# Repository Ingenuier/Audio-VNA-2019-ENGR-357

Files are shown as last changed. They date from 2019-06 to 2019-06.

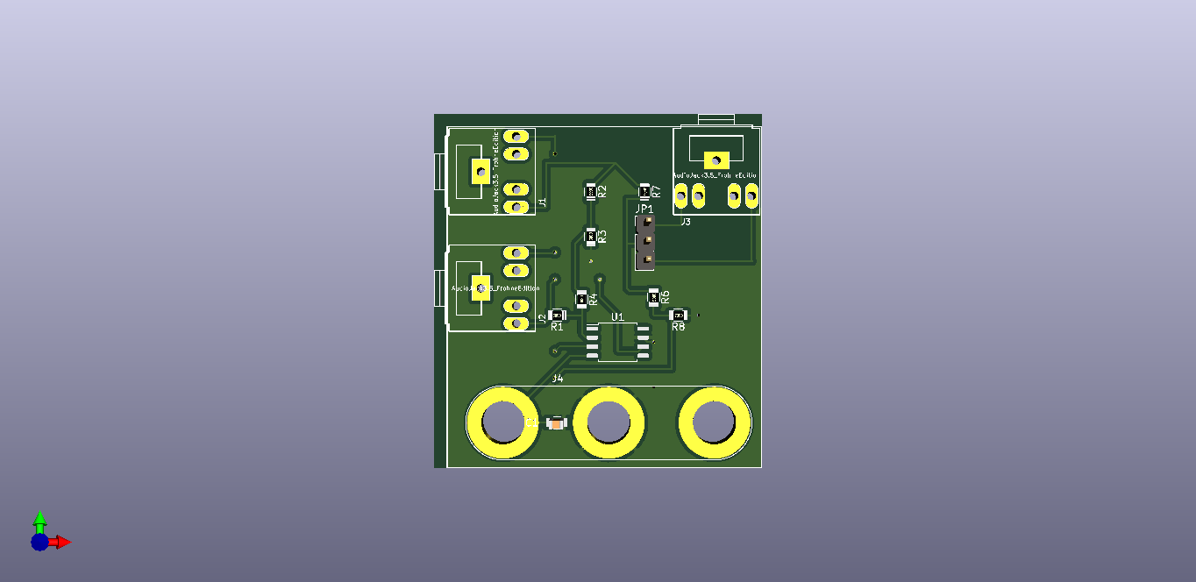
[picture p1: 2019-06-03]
KiCad/Dominick Christensen/VNA2019_KiCad Final Design/VNA2019Soundcard/VNA2019soundcard PCB PNG.png

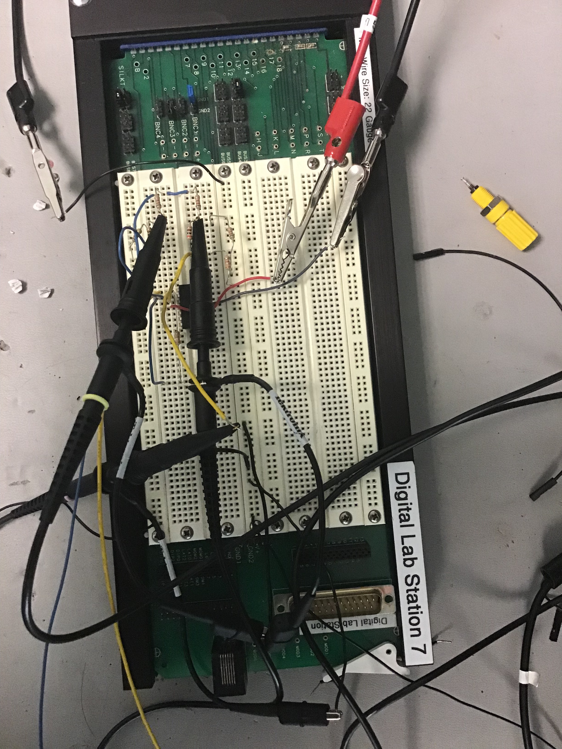
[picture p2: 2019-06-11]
PrototypeReflectionBridge.jpg

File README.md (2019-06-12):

# Audio-VNA-2019-ENGR-357
Audio Frequency VNA Project for Engineering Electronics II
Christian Terrado

These are the setup instructions for the Reflection Bridge and Sound Card, these instructions were made with the Windows OS in mind.

Software Instructions:

    -git clone the repository ( https://github.com/Ingenuier/Audio-VNA-2019-ENGR-357.git )
    -Install Python 3.7.2 and your preferred tool for executing code 
        -Tests were done using a text editor and terminal
    -In terminal, import:
        -NumPy
        -matplotlib
        -skrf (had a little trouble with this one)
        -sounddevice
        -soundfile

Hardware Instructions:

    -Plug in a 7.1 Ch Sound Card into your computer
    -Take two male to male 3.5 mm audio jacks and attach the soundcard output (headphones) into the input jack on the PCB
        -Do the same with the sound card input (microphone) and plug it into the output jack on the PCB
        -Top audio plug is input jack and bottom audio plug is output jack 
    -Use the screw terminals to supply the PCB with +/- 15V and a connection to ground on a Power Supply
        -Old physical model did not do a great job at labeling so it would be best to refer to the schematic
        -In my tests I used a HP Triple Output Power Supply
    -Use third male to male jack to connect the Device Under Test to the D.U.T Port on the PCB
        -far right audio jack is the device under test
    -Pick which channel will be tested on the reflection bridge using the jumpers next to the D.U.T Port
        -top jumper is ring, bottom is tip. 
    -Turn on the power and run the code on the PC

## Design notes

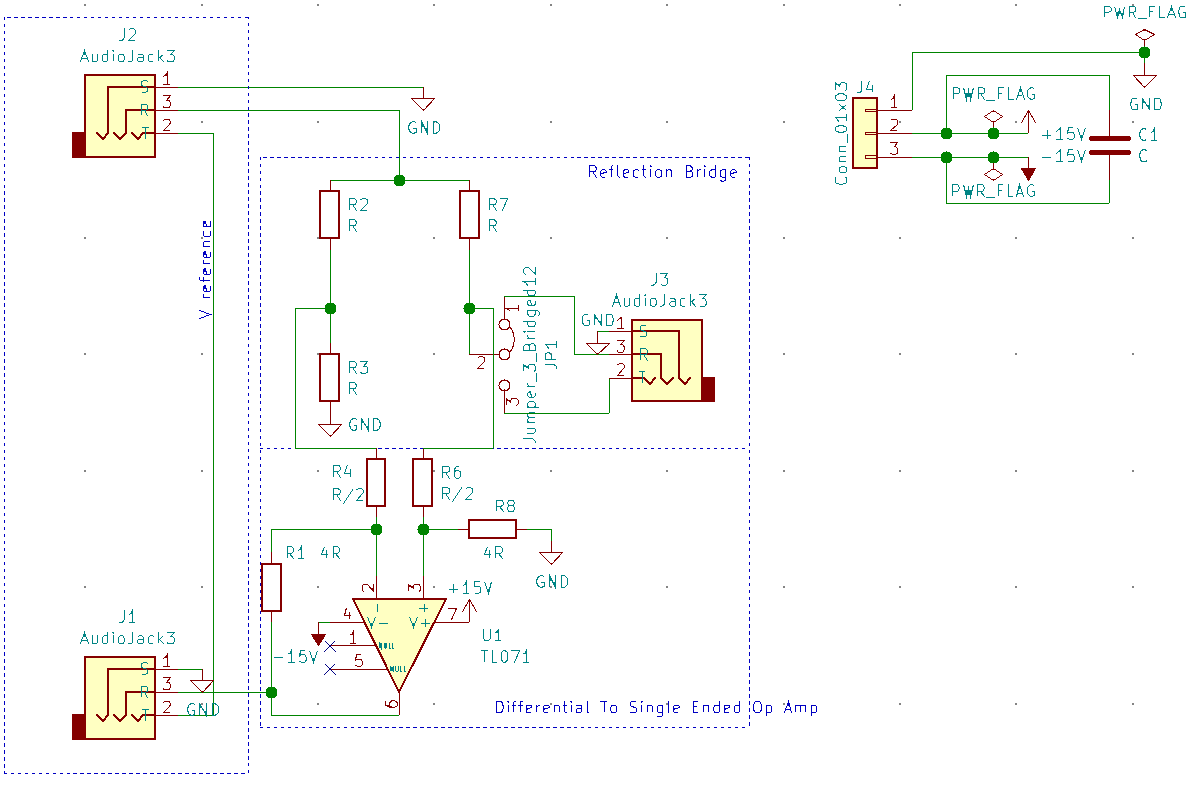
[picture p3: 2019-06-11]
CropOfSchematic.png

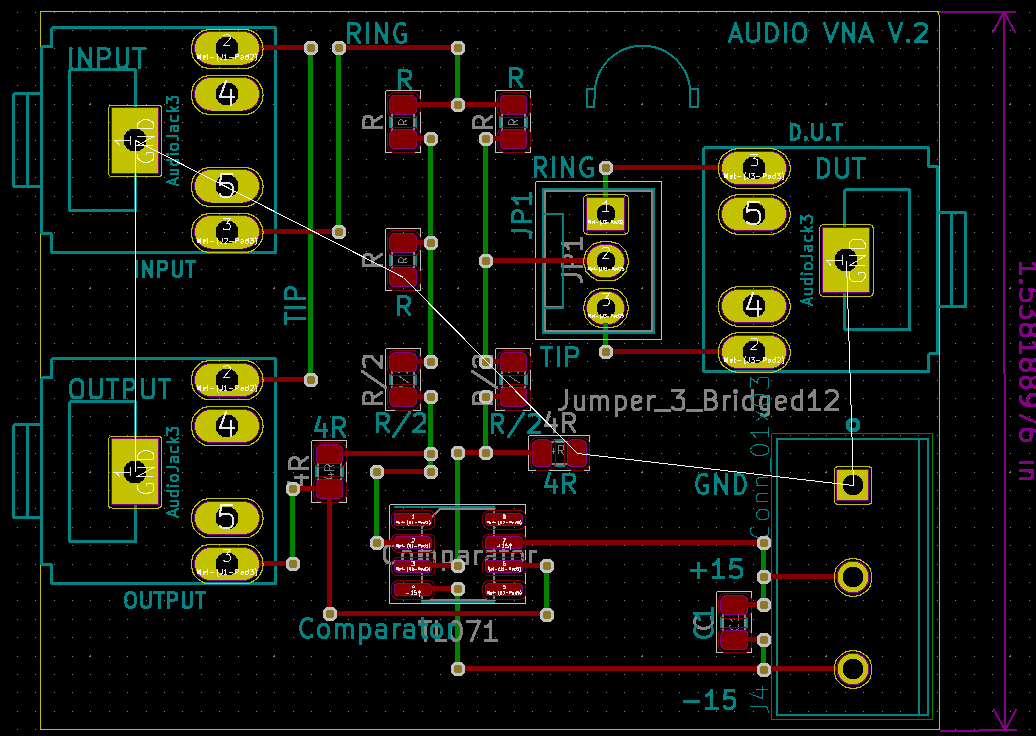
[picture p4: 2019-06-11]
CropOfVNAPCB.png

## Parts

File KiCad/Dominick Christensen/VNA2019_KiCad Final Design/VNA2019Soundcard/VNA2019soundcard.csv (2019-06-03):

Id | Designator | Package | Quantity | Designation | Supplier and ref
1 | J1,J2,J3 | Tayda_3.5mm_stereo_TRS_jack_A-853 | 3 | AudioJack3.5_FrohneEdition
2 | J4 | Banana_Jack_3Pin | 1 | Conn_01x03
3 | U1 | SOIC-8_5.23x5.23mm_P1.27mm | 1 | TL071
4 | R8,R7,R6,R4,R3,R2,R1 | R_0805 | 7 | R
5 | C1 | C_0805 | 1 | C
6 | JP1 | PinHeader_1x03_P2.54mm_Vertical | 1 | Jumper_3_Bridged12

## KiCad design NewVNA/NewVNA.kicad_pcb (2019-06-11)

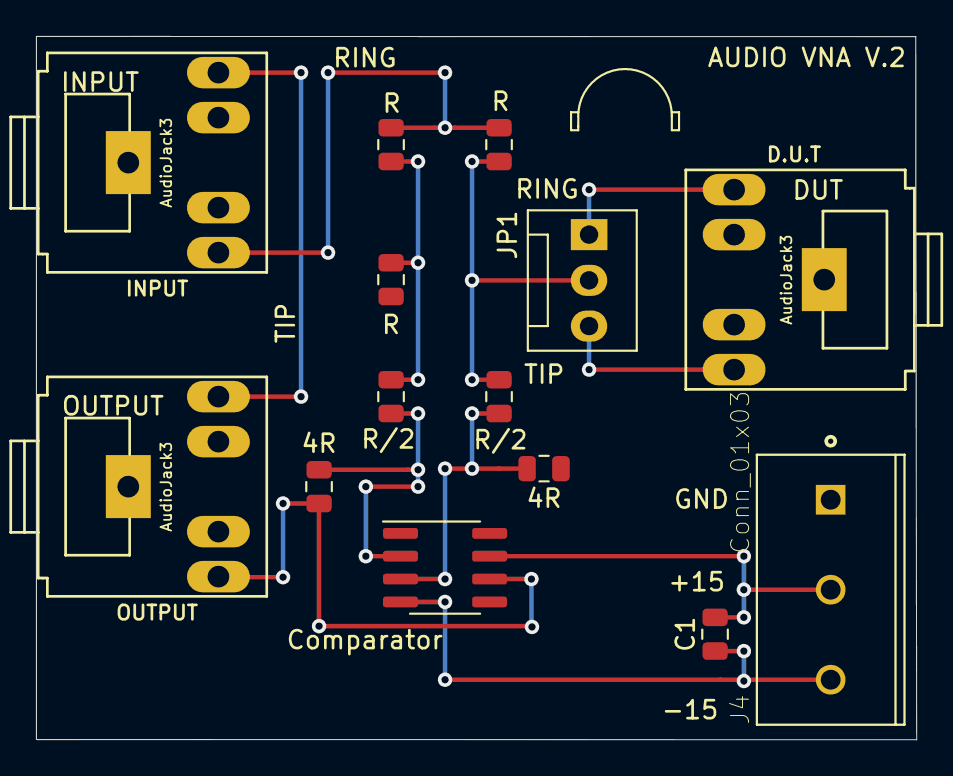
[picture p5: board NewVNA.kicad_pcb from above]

Board: 2 copper layers, 48.9 x 39.1 mm, 14 parts (0 on the bottom side), 12 nets.

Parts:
4R, 4R#2: 4R; R_0805_2012Metric
C1: C; C_0805_2012Metric
Comparator: TL071; SOIC-8_3.9x4.9mm_P1.27mm
D.U.T: AudioJack3; Tayda_3.5mm_stereo_TRS_jack_A-853
INPUT: AudioJack3; Tayda_3.5mm_stereo_TRS_jack_A-853
J4: Conn_01x03; TE_282836-3
JP1: Jumper_3_Bridged12; FanPinHeader_1x03_P2.54mm_Vertical
OUTPUT: AudioJack3; Tayda_3.5mm_stereo_TRS_jack_A-853
R: R; R_0805_2012Metric
R#2, R#3: R; R_0805_2012Metric
R/2, R/2#2: R/2; R_0805_2012Metric

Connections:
+15V: C1.1, Comparator.7, J4.2
-15V: C1.2, Comparator.4, J4.3
GND: 4R.1, D.U.T.1, INPUT.1, J4.1, OUTPUT.1, R#2.2
unnamed: INPUT.2, OUTPUT.2
unnamed: 4R#2.2, Comparator.6, OUTPUT.3
unnamed: INPUT.3, R.1, R#3.1
unnamed: D.U.T.2, JP1.3
unnamed: D.U.T.3, JP1.1
unnamed: JP1.2, R.2, R/2.1
unnamed: 4R#2.1, Comparator.2, R/2#2.2
unnamed: R#2.1, R#3.2, R/2#2.1
unnamed: 4R.2, Comparator.3, R/2.2

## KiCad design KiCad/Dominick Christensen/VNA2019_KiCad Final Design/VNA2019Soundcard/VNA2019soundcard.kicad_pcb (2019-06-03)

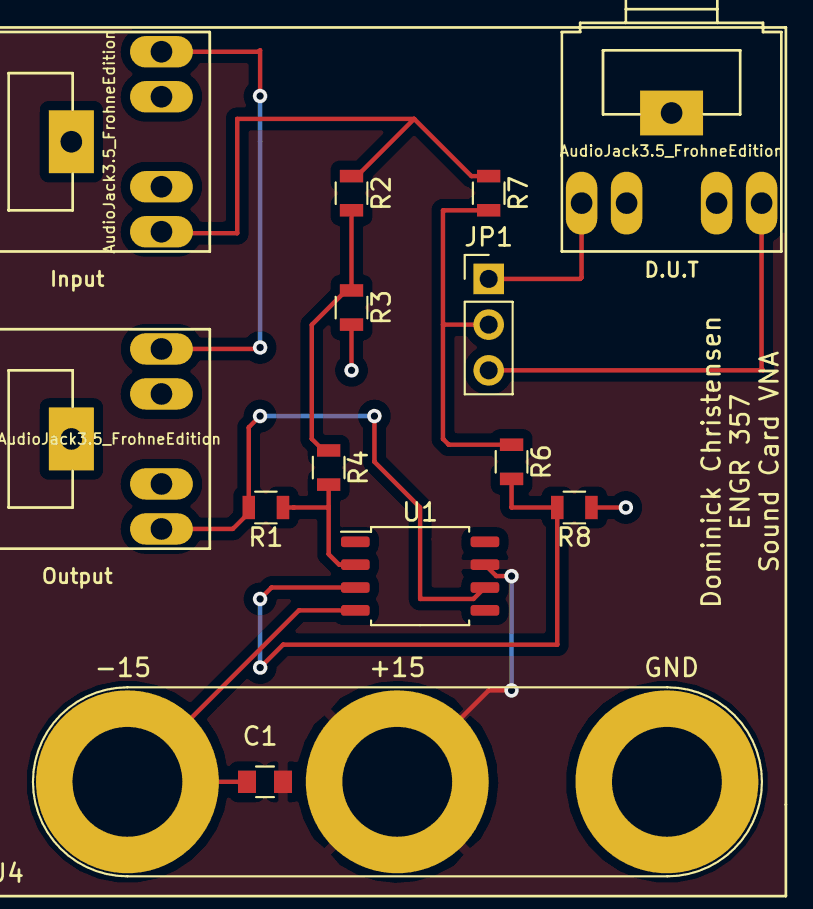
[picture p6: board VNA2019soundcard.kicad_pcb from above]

Board: 2 copper layers, 14 parts (0 on the bottom side), 12 nets.

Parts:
C1: C; C_0805
D.U.T: AudioJack3.5_FrohneEdition; Tayda_3.5mm_stereo_TRS_jack_A-853
Input: AudioJack3.5_FrohneEdition; Tayda_3.5mm_stereo_TRS_jack_A-853
J4: Conn_01x03; Banana_Jack_3Pin
JP1: Jumper_3_Bridged12; PinHeader_1x03_P2.54mm_Vertical
Output: AudioJack3.5_FrohneEdition; Tayda_3.5mm_stereo_TRS_jack_A-853
R1, R2, R3, R4, R6, R7, R8: R; R_0805
U1: TL071; SOIC-8_5.23x5.23mm_P1.27mm

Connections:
+15V: C1.1, J4.2, U1.7
-15V: C1.2, J4.1, U1.4
GND: D.U.T.1, Input.1, J4.3, Output.1, R3.2, R8.1
unnamed: Input.2, Output.2
unnamed: Input.3, R2.1, R7.1
unnamed: Output.3, R1.2, U1.6
unnamed: D.U.T.2, JP1.3
unnamed: D.U.T.3, JP1.1
unnamed: JP1.2, R6.1, R7.2
unnamed: R1.1, R4.2, U1.2
unnamed: R2.2, R3.1, R4.1
unnamed: R6.2, R8.2, U1.3

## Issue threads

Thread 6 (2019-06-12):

PCB lacking test points on board

Ingenuier, 2019-06-12:
the PCB layout for the reflection board lacks probing points for making measurements with an oscilloscope easy. Can be fixed by updated eschema files in KiCad project folder.

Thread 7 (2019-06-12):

Calibration for the Gamma

ChrisAnnTerra, 2019-06-12:
Code needs to calibrate the data so that open reads a gamma of 1, short reads gamma of -1, and ZL=Z0 reads gamma of 0.

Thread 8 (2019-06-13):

Time domain plots don't agree with expected results....

frohro, 2019-06-13:
Time domain plots, especially for the short are not what is expected.  You need to go back to the reflection bridge, use the scope and check to see if they agree with the python plots.  The phase is wrong.  You need to verify using both right and left channels connected so they measure the very same signal, that the python program also measures the same signal, and there isn't a delay or something between channels.

frohro, 2019-06-13:
You could also verify that your breadboard and your PCB give the same results on the scope.

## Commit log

2019-05-13 Add files via upload
    Updated May 12, 2019 added ground and power to op amp. Successfully passed electrical rules test
    [VNA2019soundcard.sch]
2019-06-03 added my kicad files -Dominick
    [VNA2019soundcard-B_Cu.gbr, VNA2019soundcard-B_Mask.gbr, VNA2019soundcard-B_Paste.gbr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]
2019-06-05 Cleaning up the repository
    [NewVNA-B_Cu.gbr, NewVNA-B_Mask.gbr, NewVNA-B_Paste.gbr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]
2019-06-07 cleaning up the pcb schematic and some comments on the code
    [NewVNA.kicad_pcb]
